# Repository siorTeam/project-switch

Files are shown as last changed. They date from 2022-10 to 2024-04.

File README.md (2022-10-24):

# Project Switch

블루투스 전등 스위치 Project

Pretotype v0.1 (221006)

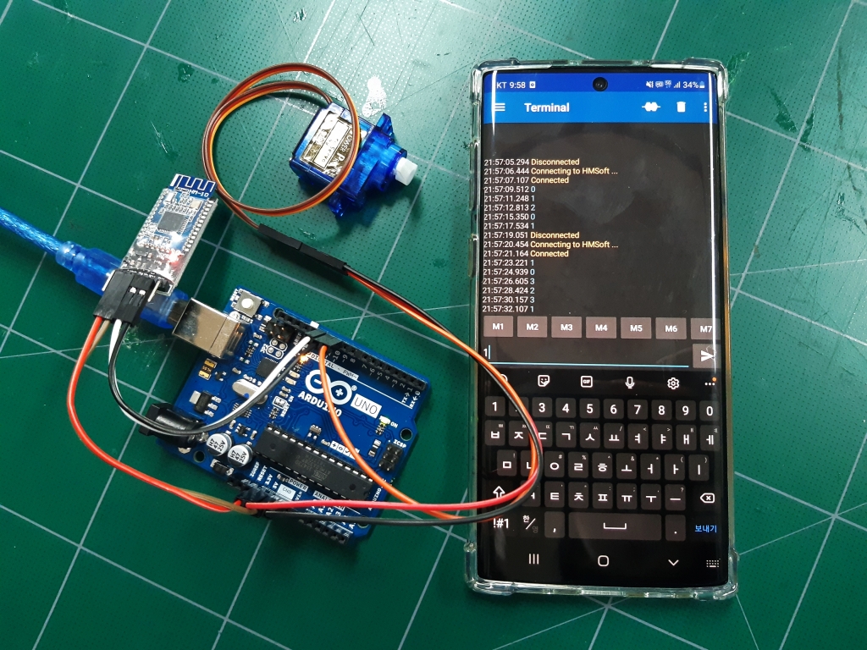
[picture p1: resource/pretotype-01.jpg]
Pretotype v0.1


## File Structure

- [`3D-model/`](3d-model/) : 3D 모델링에 대한 자료를 모아두는 폴더
- [`code/`](code/) : 소스코드를 모아두는 폴더
- [`meeting-minutes/`](meeting-minutes/) : 회의록 모아두는 폴더
- [`resource/`](resource/) : 기타 이미지, 자료들을 모아두는 폴더
- [`abstract.md`](abstract.md) : 전체 구상에 대한 개략적 소개

## 시제품 목록

보다 가성비 있는 제작을 위해 비용 대조 및 디자인 참조를 위한 시제품 목록

[실제 시제품 리스트](https://github.com/siorTeam/project-switch/issues/1)

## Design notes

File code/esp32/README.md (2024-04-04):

# ESP32

## IDE set up

아두이노 IDE에서 ESP32에 코드를 이식하기 위한 준비 방법입니다.

### Arduino IDE Set-up

1. `환경설정`을 선택
   1. 추가적인 보드 매니저 URLs의 항목에 아래의 내용을 입력(또는 옆의 창 버튼 클릭후 추가)
   2. `https://dl.espressif.com/dl/package_esp32_index.json`
2. `보드매니저`를 선택
   1. `esp32`를 검색하여 설치(`Espressif Systems`의 패키지)
3. `툴 > 보드`를 `ESP32 Dev Modules`로 설정합니다

### Library manager
1. ESP32servo by Kevin Harrington, John ~~ 을 다운로드 받는다
   
### Driver Set-up

ESP32 보드에 있는 CP2102 칩(시리얼 통신 칩)의 드라이버를 설치합니다.

아래의 홈페이지에서 다운로드 해줍니다

https://www.silabs.com/developers/usb-to-uart-bridge-vcp-drivers?tab=downloads

64비트 Windows의 경우, `CP210xVCPInstaller_x64.exe`를 실행해줍니다

## `esp32.ino`

Processor에 해당하는 ESP32 개발보드에 업로드되는 코드입니다

- 단말기(스마트폰)에서
  - '0'을 보내면 초기각도(91도)로 설정
  - '1'을 보내면 75도로 설정
  - '2'을 보내면 110도로 설정
- 각도 설정후, 0.7초 뒤에 토크가 풀림

## Pin Setting

ESP32 보드와 연결하는 핀 구성은 아래와 같습니다

ESP32 Board Pin | Servo Pin
----|----
  5V|Servo VCC
 GND|Servo GND
 P13|Servo PWM

## Reference

- https://en.wikipedia.org/wiki/ESP32
- https://github.com/siorTeam/project-switch/issues/4
- https://github.com/espressif/arduino-esp32

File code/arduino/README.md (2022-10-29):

# Arduino

## `arduino.ino`

Processor에 해당하는 Arduino에 업로드되는 코드입니다

## Pin Setting

Arduino와 연결하는 핀 구성은 아래와 같습니다

Arduino Pin | Otherside Pin
----|----
3.3V|Bluetooth VCC
  5V|Servo VCC
 GND|Bluetooth GND & Servo GND
 D12|Bluetooth TXD
 D11|Bluetooth RXD
 D10|Servo PWM

## Reference

- https://www.arduino.cc/reference/en/libraries/servo/
- https://docs.arduino.cc/learn/built-in-libraries/software-serial

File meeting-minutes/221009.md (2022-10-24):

# 221009

## 내부 디자인

- 블루투스 -> 컨트롤러
- 컨트롤러 -> 모터
- 컨트롤러 <- 배터리
- 모터 <- 배터리

## 컨트롤러 선정

- 아두이노 family(블루투스 별도)
- 👉ESP32

## 손으로도 누를 수 있게

1. 신호를 보낸 후, 초기 상태로 -> 결과적으로 토크 해제가 필요
2. ~~탄성으로 방법 -> 어떤 탄성체 감이 잡히질 않는다. 도와줘~~
3. 👉토크를 해제(일정 시간=회전 시간 이후 해제) -> 최소 시간 = (300+)ms

### 배터리

- 필요 전력?
  - 마이크로컨트롤러 작동 전위
    - 아두이노: 5V
    - ESP: 3.3V
  - 서보모터
    - (MIN:4.8, MAX:5, TYP:5)

- 종류
  - 👉코인형
  - 실린더형
  - 리포형
  - 필요한 전력을 우선적으로 고려, 차선 고려로 크기

## 배터리, 블루투스, 내부회로

- 구매후 측정-> 크기
- 연결구조
- 배터리 교체가능하게

---

## 외부 디자인 고려

스위치당 필요기능 2가지(소등/점등)
스위치당 모터를 1개를 할지? 2개를 할지?

### 어떻게 누를 것인가?

- 스위치)에 뽁뽁이-돌출부(?)를 추가적으로 부착해서 누르기 편하게
- 회전 -> 직선운동: https://youtu.be/hsaoTo1vuY4 (동작범위가 적음 목표)
- 모터+작용축 그런거

## 3D 모델링(프린팅용)

- 👉Autodesk 인벤터 -> 물리적인 테스트 가능
- ~~블렌더~~

미리 설치 시도를 해볼 것(사양 검사 과정에서 탈락여부확인)

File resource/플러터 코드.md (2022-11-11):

[플러터 코드](https://github.com/flutter/samples/tree/main/platform_design)

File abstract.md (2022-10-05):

Project Switch
===

# Architecture

## Communication

무선 통신 방법
- RF
  - 이동통신(2~5G)
  - 위성통신
- NFC
- bluetooth
- wifi
- Zigbee
- Z-wave

👉 **블루투스**로 제어

- 모바일 환경(스마트폰)에서 쉽게 제어가능 해야함(사용편의성)
- 실내 근거리 통신에 적합
- 낮은 전력과 비용
- 안드로이드, iOS 모두 동작해야함
  - Bluetooth Classic    (iOS에서 지원하지 않음)
  - Bluetooth Low Energy (BLE = bluetooth 4.0이상 버전)이 호환되어야 함

### Bluetooth 4.0+
- Hardware Module
  - HM-10
    - 3.3V, UUID: 0xFFE0
    - AT-COMMAND
- Software Module(App)
  - software reuse
    - Android : `Serial Bluetooth Terminal`
    - iOS     : `BitBlue`
  - customizing App
    - (ios, android)모두 호환, 빠르게 구현
    - 중간고사 끝나고 퍼포먼스/와이어프레임 결정
    - 구현 요소
      - GUI(Graphic User Interface): 버튼위젯 / 목록 위젯
      - 블루투스 연결
      - 추가사항 (알람기능, ...)
    - candidate SW tool
      - flutter (3시간)
      - ~~React native~~
      - unity (3시간+)

## Actuation

👉 **서보모터**로 제어
- 각도 제어와 강한 토크 전달이 주요 요인

### 서보모터 리스트

- 👉 SG90
  - 낮은 비용
  - 적은 무게
  - 작은 크기
- MG90S
- MG996R
- HS-311

## Physics Model

캐비넷 - 3D 프린팅

# Additional 

## 추가 고려사항
- 블루투스 동작과정
  - 블루투스 페어링
- 스위치는 수동으로도 누를 수 있게
  - 서보모터에 신호가 왔을 때만 동작 이후는 토크가 걸리지 않게(수동이 가능하게)
- 스위치 개수가 증가했을 때 원활히 관리방법
- 캐비넷 디자인
- 필요 전력 최소화?

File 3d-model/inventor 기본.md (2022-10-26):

# 221026
## 기초적인 조작
- 수평 이동 ; 휠 클릭
- 회전 ; shift + 휠 클릭
- 작성 스탠다드(mm).ipt
- 조립품 = 부품 드래그 앤 드랍 [검은 점] - 고정 돼 있다는 뜻
- 선택은 다 좌클릭

## 2D 만들기
- 레이어 많이 만들어내기
- 부품이 달라야 동작 가능 
- 2D 스케치 , 아무 면이나 클릭, 
- 보라색 ; 모든 구속조건[치수] 아직 완료 되지 않음 _ 이동 가능
- 검은색 ; 모든 구속조건 완료 _ 고정 => 3D 생성 가능
- esc 선 취소 
- ctrl c , z , v 다 가능
- 모든 것은 닫힌 곡선이어야 함

## 3D 만들기
- 쉘 ; 틀만 남음 _ 겉에선 안보일 수 있음 ; 뷰 들어가서 안쪽 확인
- 회전 : 중심선(회전축)이 필요함
- 평면 있어야 -> 작업 가능
- 엠보싱 : 글자 새기기

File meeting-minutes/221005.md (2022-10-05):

# 221005

## 1. 중간 발표 준비(22.10.07 금요일)

- [x] 구체적인 목표 (스위치를 침대에 누워서 끌 수 있게, +추가기능:알람기능/스위치다수제어, 수명:18개월, 가격:50000원(가성비), 크기:스위치도작게)
- [x] 전시회 준비 과정의 진행상태(프리토타이핑 완성)
- [x] 진행 계획

## 2. 사전 준비 사항

- 3D 프린팅 방법
	- [러닝팩토리 프린팅 가이드](https://sites.google.com/site/skkulf/Manual/3DP)

- 3D 모델링 방법
	- 소프트웨어 도구
		- 인벤터(컴퓨터 하이스펙이 필요)

## 3. 전체 스케줄 계획

**spiral development**

전체 내부 디자인(모터 별도)
-> (외부 디자인 + 모터, 케이스 3D 프린팅)
-> 프로토타입
-> 앱 구현
-> 최종 시안

## 4. 세부 스케줄 계획

- 10/07 : 중간발표
- 10/09 : 배터리, 블루투스, 내부회로 -> (모터 / 내부 회로 / 배터리) 크기 고려

~ 중간고사기간 ~

(여유로울 때, 3D 모델링 스터디 병행)

- 10/23 : 디자인1 모터각도 설계, 시중에서 사용하는 토크 전달 방법(탄성체 이용?)
- 10/26 : 디자인2
- 10/30 : 디자인3
- 11/ 2 : 프로토타입(1개-) (첫 테스트 - 안드로이드)
- 11/ 6 : (테스트 기간 - 앱구조 디자인)
- 11/ 9 : 앱 개발
- 11/13 : 예비
- 11/16 : 예비
- 11/18-19 : 최종발표 (최종시안)

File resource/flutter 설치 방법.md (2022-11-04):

- [플러터 설치_윈도우즈](https://docs.flutter.dev/get-started/install/windows)
- [플러터 설치 방법](https://bangu4.tistory.com/310)
- [안드로이드 스튜디오](https://crazykim2.tistory.com/455)

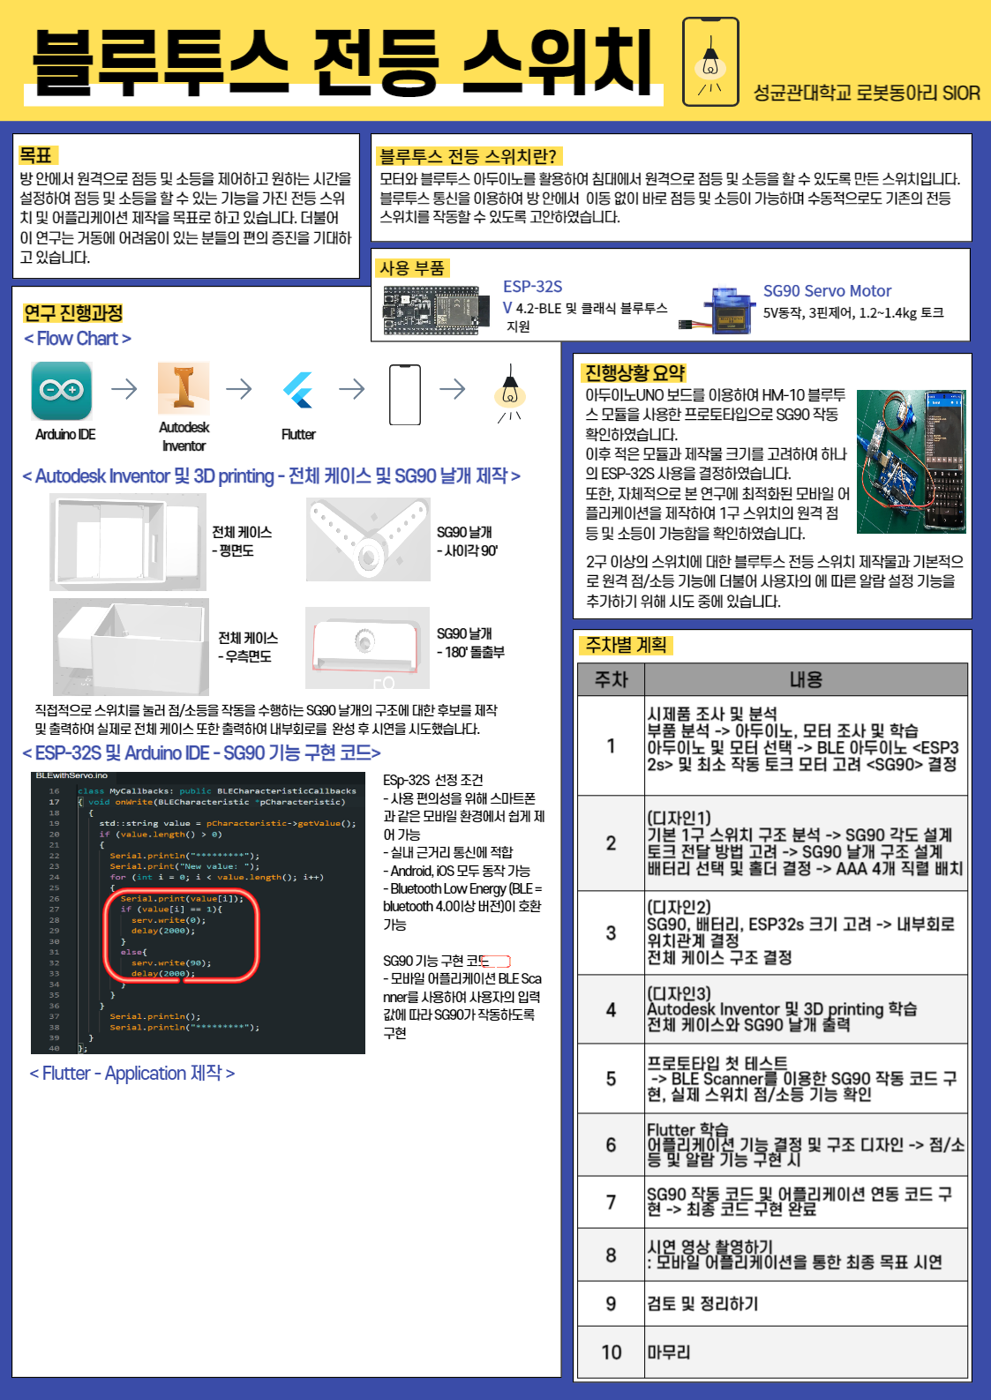
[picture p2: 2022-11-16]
sior_블루투스전등스위치_flutter공백.png

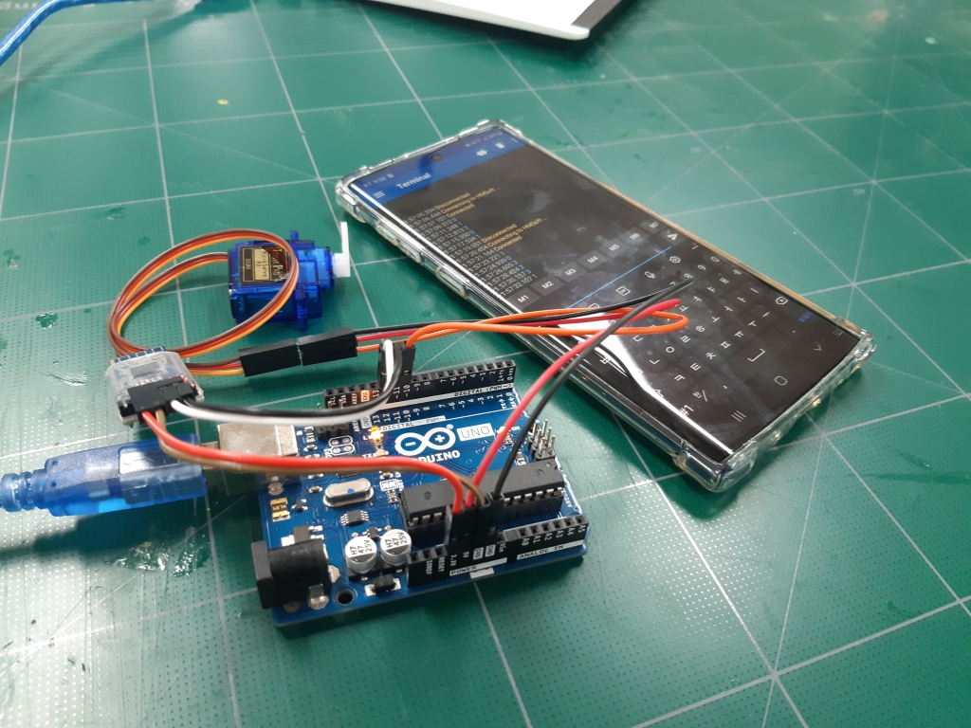
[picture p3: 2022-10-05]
resource/pretotype-02.jpg

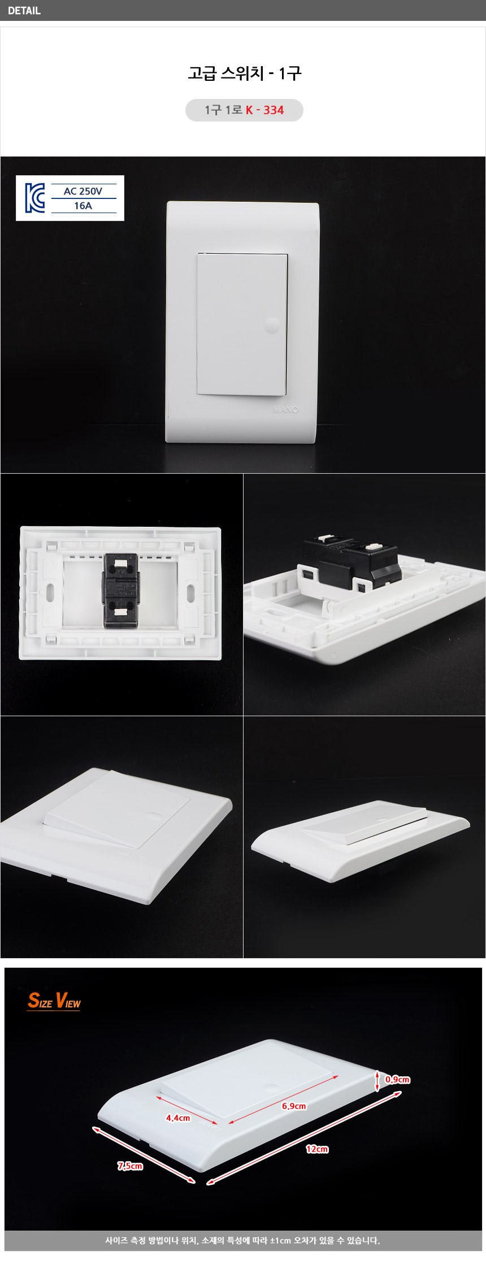
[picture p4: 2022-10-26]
resource/1구 스위치.jpg

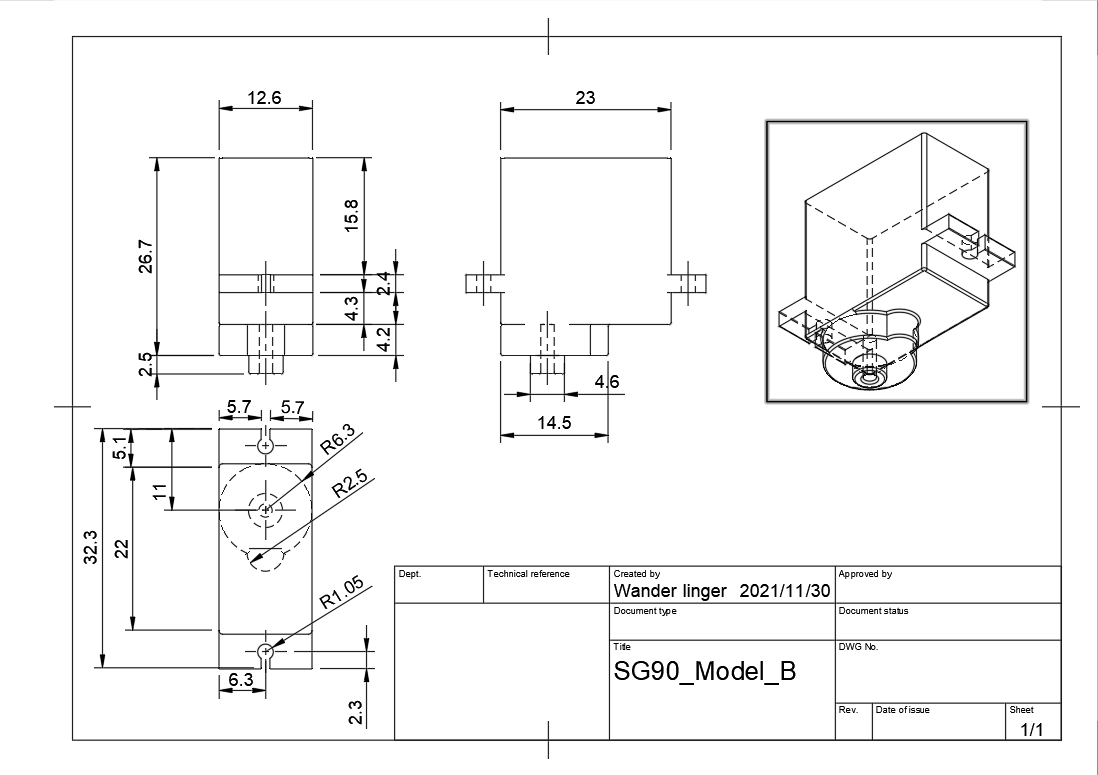
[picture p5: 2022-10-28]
3d-model/SG90_Model_B.png

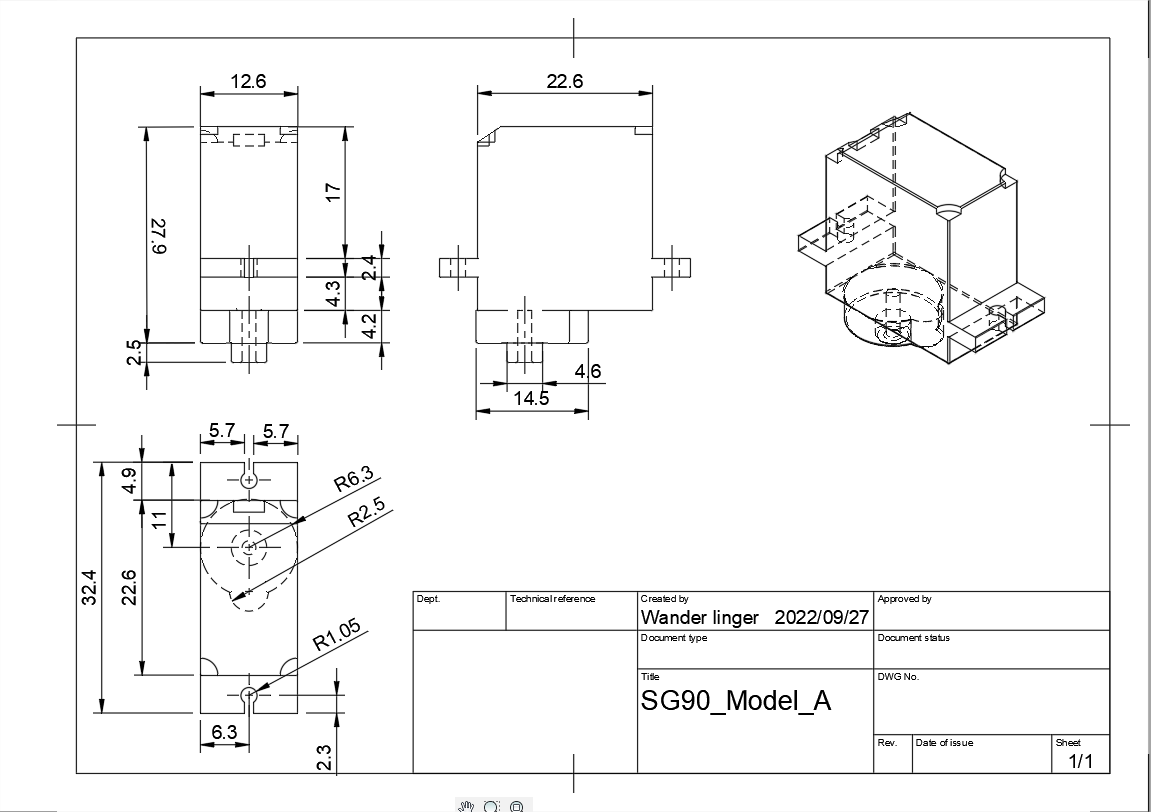
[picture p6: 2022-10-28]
3d-model/SG90_Model_A.png

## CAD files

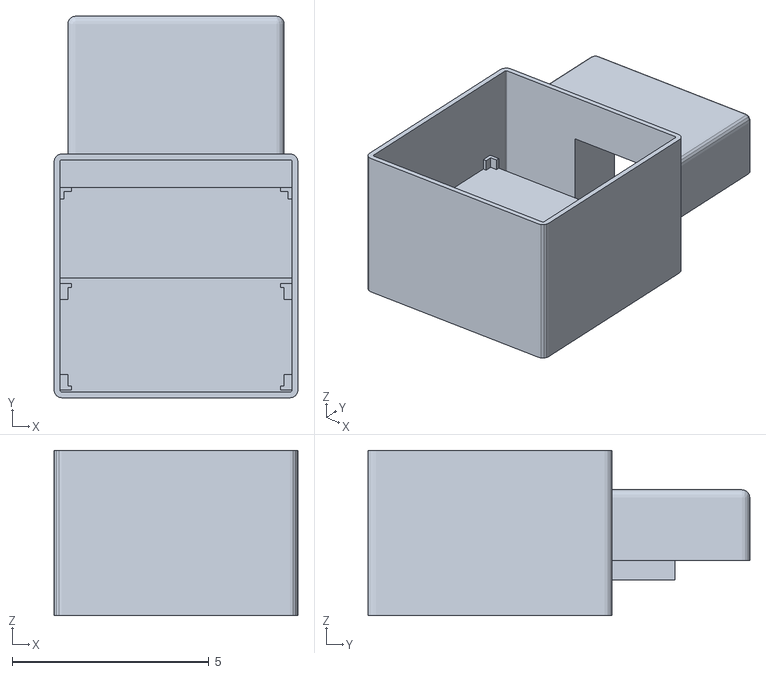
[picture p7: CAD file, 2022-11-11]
3d-model/케이스_수정_2.stl
6.20 x 9.70 x 4.20

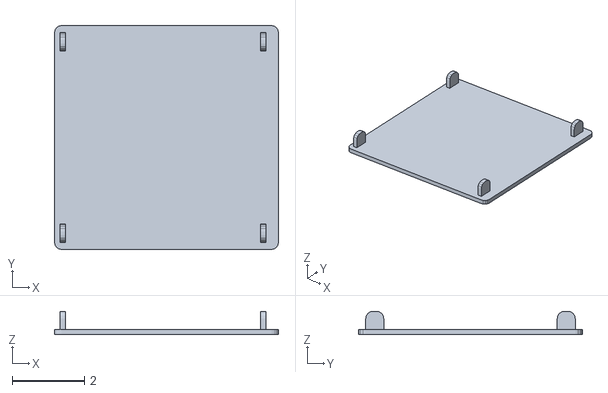
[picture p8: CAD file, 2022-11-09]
3d-model/뚜껑_수정.stl
6.20 x 6.20 x 0.65

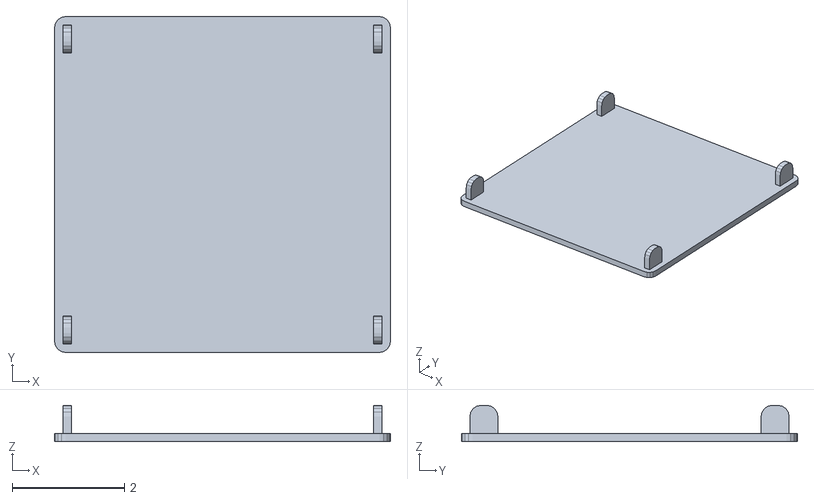
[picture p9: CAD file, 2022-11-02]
3d-model/뚜껑.stl
6.00 x 6.00 x 0.65

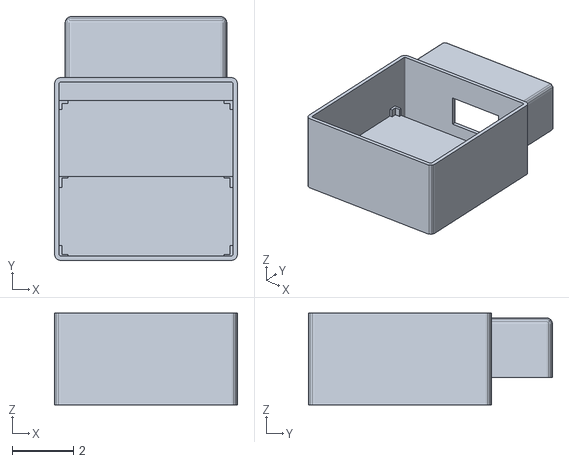
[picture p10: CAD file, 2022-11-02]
3d-model/케이스.stl
6.00 x 8.00 x 3.00

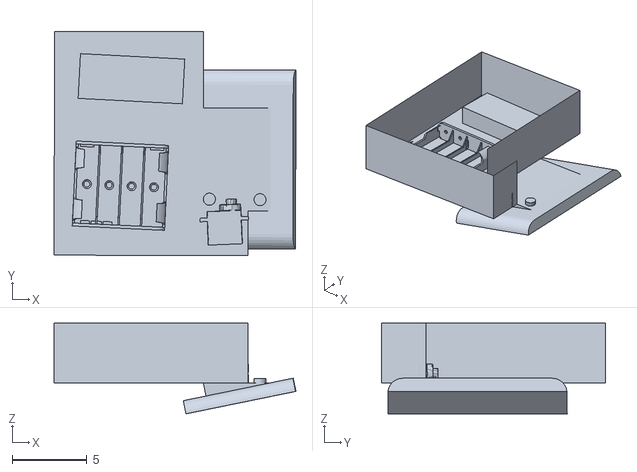
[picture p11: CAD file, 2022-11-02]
3d-model/스위치및케이스내부구성도.stl
16.2 x 15.0 x 6.07

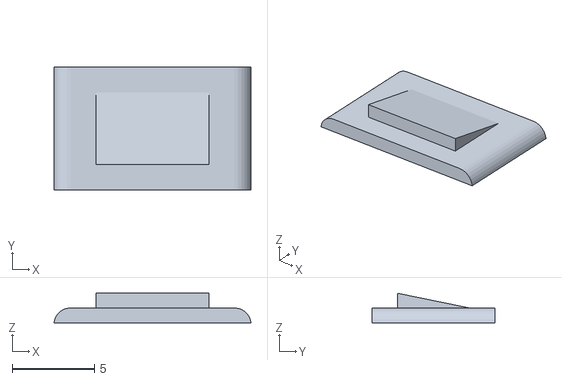
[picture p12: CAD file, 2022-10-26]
3d-model/스위치.stl
12.0 x 7.50 x 1.80

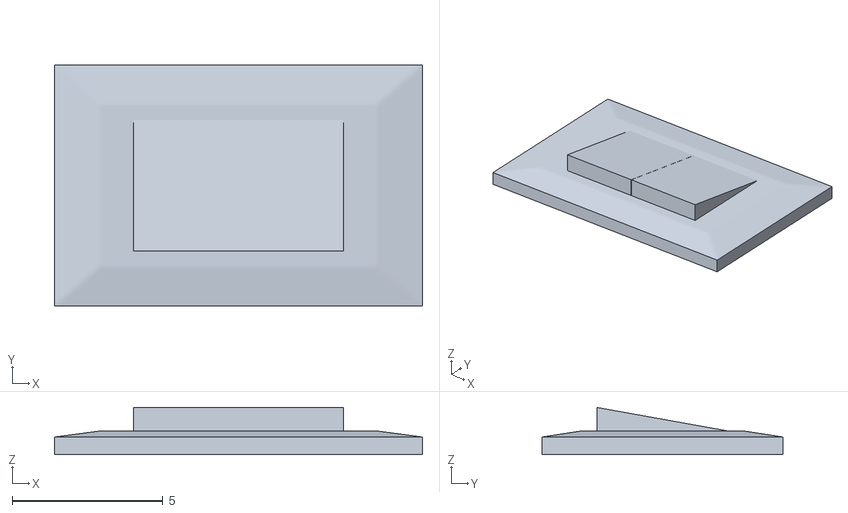
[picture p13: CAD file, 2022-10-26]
3d-model/스위치2.stl
12.2 x 8.00 x 1.56

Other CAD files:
3d-model/케이스_수정.stl
3d-model/SG90_Arm1.9rad.ipt
3d-model/SG90_Arm9090.ipt
3d-model/SG90_Arm_01 v6.ipt
3d-model/SG90_Model_A v4.ipt
3d-model/SG90_Model_B.ipt
3d-model/동작/동작.iam
3d-model/동작/배경.ipt
3d-model/동작/수직축.ipt
3d-model/동작/슬롯.ipt
3d-model/동작/원.ipt
3d-model/동작/축 케이스.ipt
3d-model/동작/축.ipt
3d-model/디귿자 날개.ipt
3d-model/스위치.ipt
3d-model/스위치2.ipt
3d-model/스위치및케이스내부구성도.iam
3d-model/스카치 요크/뚫린 직육면체.ipt
3d-model/스카치 요크/스카치 요크.iam
3d-model/스카치 요크/작은 원통.ipt
3d-model/스카치 요크/큰 원통.ipt

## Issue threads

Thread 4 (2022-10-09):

ESP32S with servo

terracass, 2022-10-09:
https://www.techcoil.com/blog/how-to-control-a-servo-motor-with-an-esp32-development-board/

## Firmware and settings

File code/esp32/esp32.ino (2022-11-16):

/**
 * @file esp32.ino
 * @author switch-team, siorTeam
 * @version 0.6.2
 * @date 2022-11-16
 * 
 * @copyright Copyright (c) 2022
 * 
 */

/*****

  Video: https://www.youtube.com/watch?v=oCMOYS71NIU
  Based on Neil Kolban example for IDF: https://github.com/nkolban/esp32-snippets/blob/master/cpp_utils/tests/BLE%20Tests/SampleNotify.cpp
  Ported to Arduino ESP32 by Evandro Copercini

  The design of creating the BLE server is:
  1. Create a BLE Server
  2. Create a BLE Service
  3. Create a BLE Characteristic on the Service
  4. Create a BLE Descriptor on the characteristic
  5. Start the service.
  6. Start advertising.

*****/

#include <BLEDevice.h>
#include <BLEServer.h>
#include <BLEUtils.h>
#include <BLE2902.h>
#include <ESP32Servo.h>

Servo serv; 

BLEServer *pServer;
BLEService *pService;
BLECharacteristic *pTxCharacteristic;
BLECharacteristic *pRxCharacteristic;
bool deviceConnected    = false;
bool oldDeviceConnected = false;

#define SERVICE_UUID           "6E400001-B5A3-F393-E0A9-E50E24DCCA9E" // UART service UUID
#define CHARACTERISTIC_UUID_RX "6E400002-B5A3-F393-E0A9-E50E24DCCA9E"
#define CHARACTERISTIC_UUID_TX "6E400003-B5A3-F393-E0A9-E50E24DCCA9E"

class MyServerCallbacks: public BLEServerCallbacks {
  void onConnect(BLEServer* pServer) {
    deviceConnected = true;
  };

  void onDisconnect(BLEServer* pServer) {
    deviceConnected = false;
  };
};

class MyCallbacks: public BLECharacteristicCallbacks {
  void onWrite(BLECharacteristic *pCharacteristic) {
    std::string rxValue = pCharacteristic->getValue();

    if (rxValue.length() > 0) {
      Serial.println("*********");
      Serial.print("Received Value: ");

      // values for TowerPro SG90
      // https://github.com/jkb-git/ESP32Servo/blob/master/src/ESP32_Servo.h
      serv.attach(13, 400, 2400);
      for (int i = 0; i < rxValue.length(); i++) {
        Serial.print(rxValue[i]);

        if ('0' <= rxValue[i] && rxValue[i] <= '2') {
          if('0' == rxValue[i])       serv.write(91);
          else if('1' == rxValue[i])  serv.write(91-16);
          else if('2' == rxValue[i])  serv.write(91+19);
          delay(700);
        }

      }
      serv.detach();
    }
  }
};

void setup() {
  Serial.begin(115200);
  serv.setPeriodHertz(50);

  // Create the BLE Device
  BLEDevice::init("remote-SW");

  // Create the BLE Server
  pServer = BLEDevice::createServer();
  pServer->setCallbacks(new MyServerCallbacks());

  // Create the BLE Service
  pService = pServer->createService(SERVICE_UUID);

  // Create a BLE Characteristic
  pTxCharacteristic = pService->createCharacteristic( CHARACTERISTIC_UUID_TX, BLECharacteristic::PROPERTY_NOTIFY );
  pTxCharacteristic->addDescriptor(new BLE2902());

  pRxCharacteristic = pService->createCharacteristic( CHARACTERISTIC_UUID_RX, BLECharacteristic::PROPERTY_WRITE );
  pRxCharacteristic->setCallbacks(new MyCallbacks());

  // Start the service
  pService->start();

  // Start advertising
  pServer->getAdvertising()->start();
  Serial.println("Waiting a client connection to notify...");

  // Setting initial angle
  serv.attach(13, 400, 2400);
  serv.write(91);
  delay(500);
  serv.detach();
}

void loop() {
  // disconnecting
  if (!deviceConnected && oldDeviceConnected) {
    delay(500); // give the bluetooth stack the chance to get things ready
    pServer->startAdvertising(); // restart advertising
    Serial.println("Disconnected, Start Advertising");
    oldDeviceConnected = deviceConnected;
  }

  // connecting
  if (deviceConnected && !oldDeviceConnected) {
    Serial.println("Connected");
    oldDeviceConnected = deviceConnected;
  }
}

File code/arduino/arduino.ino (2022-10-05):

/**
 * @file arduino.ino
 * @author switch-team, siorTeam
 * @version 0.1.0
 * @date 2022-10-06
 * 
 * @copyright Copyright (c) 2022
 * 
 */

#include <SoftwareSerial.h>
#include <Servo.h>

#define PIN_BT_TX     12 
#define PIN_BT_RX     11
#define PIN_SERVO_PWM 10

// Declare module Bluetooth as UART
SoftwareSerial BT_Serial(PIN_BT_TX, PIN_BT_RX);
// Declare Servo
Servo serv;

// DEBUG :: test for getting bluetooth module informations
void test_bluetooth_connect(){
  while(BT_Serial.available()){
    Serial.write(BT_Serial.read());
  }
  while(Serial.available()){
    BT_Serial.write(Serial.read());
  }
}

void setup() {
  // set baud rate & servo pin setup
  Serial.begin(9600);
  BT_Serial.begin(9600);
  serv.attach(PIN_SERVO_PWM);

  Serial.println("READY!"); // DEBUG
  serv.write(0); // initial setting
  delay(100); // pause until servo setting finish
}

void loop() {

  // DEBUG
  // test_bluetooth_connect();

  // Is there receiving data from bluetooth
  while(BT_Serial.available()){
    byte data = BT_Serial.read(); // Get Data from bluetooth module(mobile)
    Serial.write(data); // DEBUG
    
    switch(data){
      case 0x30: serv.write(  0); break; // '0' ->   0 degree
      case 0x31: serv.write( 90); break; // '1' ->  90 degree
      case 0x32: serv.write(180); break; // '2' -> 180 degree
      case 0x33: serv.write(  0); break; // '3' ->   0 degree
    }
    delay(100); // pause until servo setting finish
  }

  // DEBUG
  while(Serial.available()){
    BT_Serial.write(Serial.read());
  }
}

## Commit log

2022-10-05 Add 221005 회의록
2022-10-05 Add arduino code
2022-10-24 Rename title of README.md
    File System -> File Structure
    시스템이라는 표현보다는 구조라는 표현이 구체적으로 나타내주어 변경
2022-10-26 Create inventor 기본.md
    10.26 inventor 설명 정리
2022-10-26 Rename inventor 기본.md to inventor 기본
2022-10-26 Update inventor 기본
2022-10-26 스위치 견본
    스위치 규격에 맞춘 임의의 스위치 부품 파일입니다.
    [스위치.ipt, 스위치2.ipt]
2022-10-26 re-upload
    to md 파일
2022-10-26 스위치 견본 미리보기
    [스위치.stl, 스위치2.stl]
2022-10-26 1구 스위치 규격.jpg
2022-10-28 SG90 servo STL File (A)
    [SG90_Arm_01 v6.ipt, SG90_Model_A v4.ipt, SG90_Model_B.ipt]
2022-10-28 scotch yoke
    [뚫린 직육면체.ipt, 스카치 요크.iam, 작은 원통.ipt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]
2022-10-28 Create ESP32 directory
2022-10-29 Update arduino code README.md
2022-10-30 Add esp32 code
2022-11-02 스위치+케이스내부구성 및 전체모형도
    [스위치및케이스내부구성도.iam]
2022-11-02 스위치및내부구성도및전체틀
    [스위치및케이스내부구성도.stl]
2022-11-02 디귿자 날개
    [디귿자 날개.ipt]
2022-11-02 뚜껑, 케이스
    [뚜껑.stl, 케이스.stl]
2022-11-04 flutter 설치 방법
2022-11-04 Update flutter 설치 방법.md
    안드로이드 스튜디오
2022-11-09 케이스, 뚜껑 수정
    [뚜껑_수정.stl, 케이스_수정.stl]
2022-11-11 Create 플러터 코드.md
2022-11-11 케이스 수정
    [케이스_수정_2.stl]
2022-11-15 Update esp32.ino with UART
2022-11-15 Update esp32.ino with Servo
2022-11-15 Update esp32.ino with servo specific
2022-11-15 Update esp32 code version
2022-11-16 Update esp32 code w/ specific angle
